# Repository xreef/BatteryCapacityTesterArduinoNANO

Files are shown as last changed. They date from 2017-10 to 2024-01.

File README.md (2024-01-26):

# Battery Capacity Tester Arduino NANO compatible #

Learn how to check battery capacity with Arduino, including essential techniques for temperature monitoring and selecting the right battery type, in my detailed article:

Checking Battery Capacity with Arduino: Temperature Monitoring and Type Selection (https://mischianti.org/checking-battery-capacity-with-arduino-temperature-monitoring-and-type-selection/)

[Link to the article](https://mischianti.org/checking-battery-capacity-with-arduino-temperature-monitoring-and-type-selection/)

This guide is a valuable resource for anyone interested in Arduino-based battery management and monitoring systems.

Battery capacity tester.
With this device you can check the 18650 battery capacity. For safe I added with thermistor the temperature of power resistance and battery to prevent explosion.
I'm doing some change from original project:
v0.1
 - VCC of Arduino now It's automatically calculated;
 - Added variable to change setting in more confortable way.
 - Added percentage of discharging
 - Added temperature of battery and power resistor
 
v0.2
 - Added possiblity of battery selection
 - Created prototype board (Look the schema), screen, button and speaker is out of board because in the future I'd like to create a package. 
  - Added manage of temperature limit for power resistor.to block when raise 70°.

In v0.2 to support various type of battery I created a struct that must be filled with battery name, min voltage, e max voltage *(I need help to fill :P)*.
```cpp
// Structure of battery type
struct BatteryType {
	char name[10];
	float maxVolt;
	float minVolt;
};

#define BATTERY_TYPE_NUMBER 4
BatteryType batteryTipes[BATTERY_TYPE_NUMBER] = {
		{ "18650", 4.3, 2.9 },
		{ "17550", 4.3, 2.9 },
		{ "14500", 4.3, 2.75 },
		{ "6v Acid", 7.2, 6.44  }
};
```
Now I use 10k resistor for voltage read, if you want change voltage support you must change this value *(explain better next)*:
```cpp
// Battery voltage resistance
#define BAT_RES_VALUE_GND 10.0
#define BAT_RES_VALUE_VCC 10.0
// Power resistor voltage resistance
#define RES_RES_VALUE_GND 10.0
#define RES_RES_VALUE_VCC 10.0
```
If you don't use thermistor set to false this:
```cpp
#define USING_BATTERY_TERMISTOR true
#define USING_RESISTO_TERMISTOR true
```
If you use a different i2c display you must rewrite this method:
```cpp
void draw(void);
```

In project you can find fritzing, schema, photo and other.

*I use generic character display, and I build the i2c controller and use It with my custom library, but if you want You can take a normal i2c controller (less than 1€) with standard library, the code remain the same.*
*All code of display is in draw function so you can change that without change other.*

Created from an idea of [OpenGreenEnergy](http://www.instructables.com/id/DIY-Arduino-Battery-Capacity-Tester-V10-/).

## Realization ##
To measuring voltage we use the principle of Voltage divider, more information on:
[Wikipedia](https://en.wikipedia.org/wiki/Voltage_divider) or [Blog](https://startingelectronics.org/articles/arduino/measuring-voltage-with-arduino/), in simple word this code 
```cpp
batVolt = (sample1 / (1023.0 - ((batResValueGnd / (batResValueVolt + batResValueGnd)) * 1023.0))) * vcc;
```
measure battery voltage,
`batResValueGnd / (batResValueVolt + batResValueGnd)` this is the multipler factor of the reading voltage, I inserted 2 resistance of `batResValueVolt` and `batResValueGnd` ohom after and before the analog read wire;
`sample1 -->` is the average analog readings;
`vcc -->` reference arduino voltage;
`1023.0 -->` is the reference maximun value of analog read (arduino analog read go from 0 to 1023)
	
The principle is that we measure the voltage afther and before the power resistor and so we can calculate milliampere that consumes the battery.

The MOSFET is used to stard and stop battery drain from power resistor.
I'm pretty scary, so I inserted 2 thermistors to monitorage battery and power resistor temperature.

### Versione v0.2 ###
---

**On prototype board:**
I create a prototype board very extendible, but for now I use only minimal set of pin (in future led and other button).
If you want support voltage greater than 10v you must change the resistor value of Battery and Resistance in according to the formula
`(BAT_RES_VALUE_GND / (BAT_RES_VALUE_VCC + BAT_RES_VALUE_GND)` in the schema `Resistor power voltage GND 1/2 / (Resistor power voltage 2/2 + Resistor power voltage GND 1/2)`.

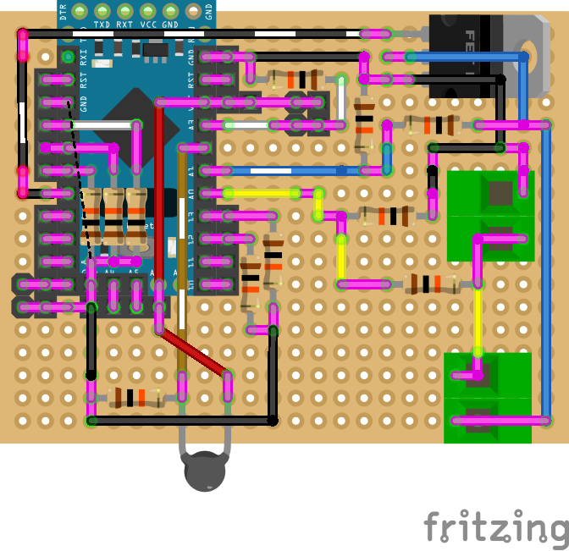
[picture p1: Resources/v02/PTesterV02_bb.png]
Prototype


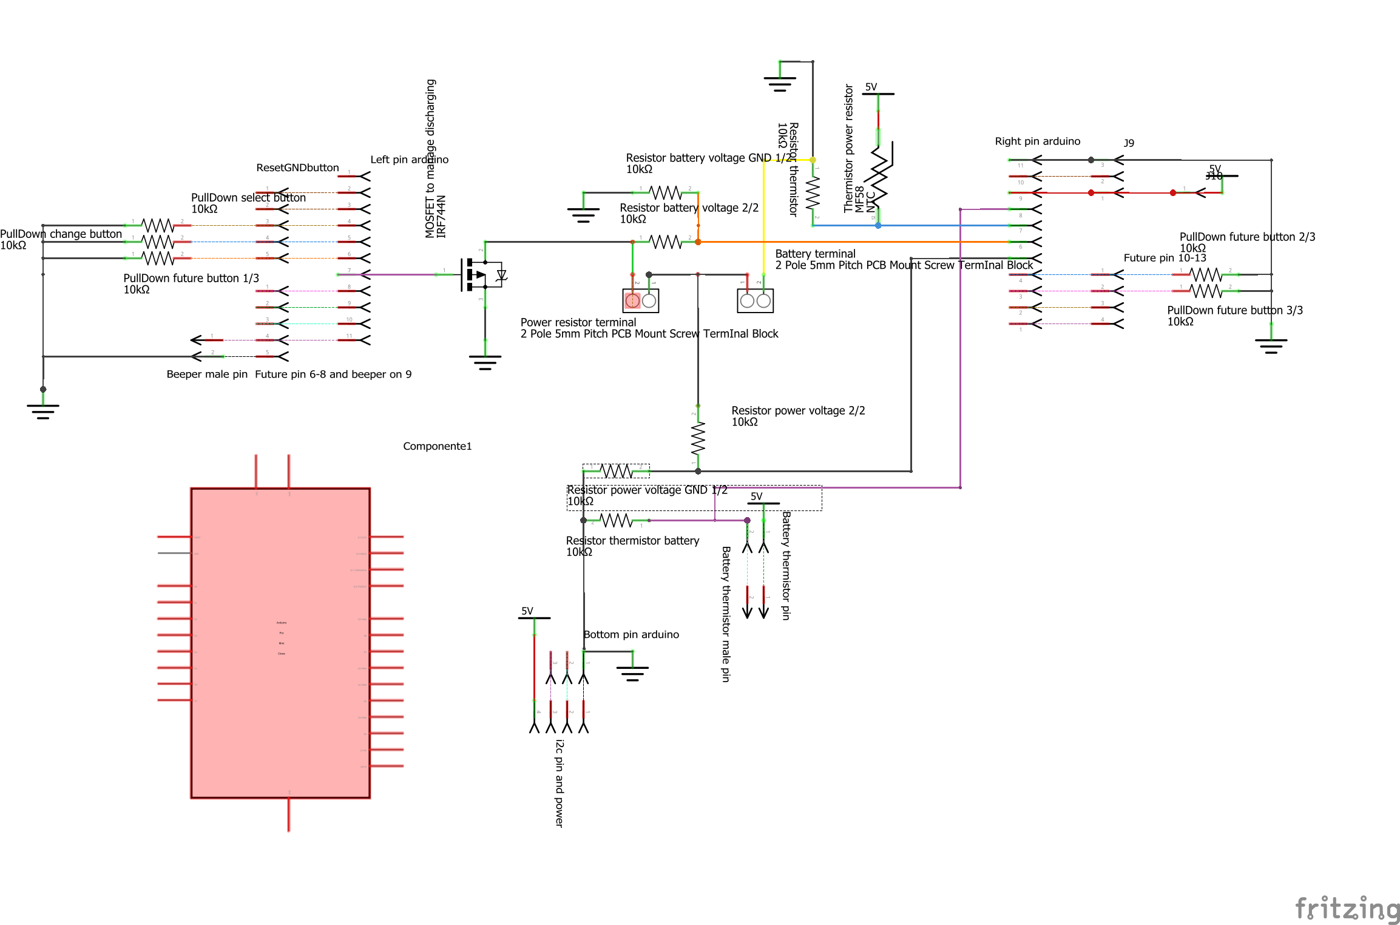
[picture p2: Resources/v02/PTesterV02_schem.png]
Prototype schema


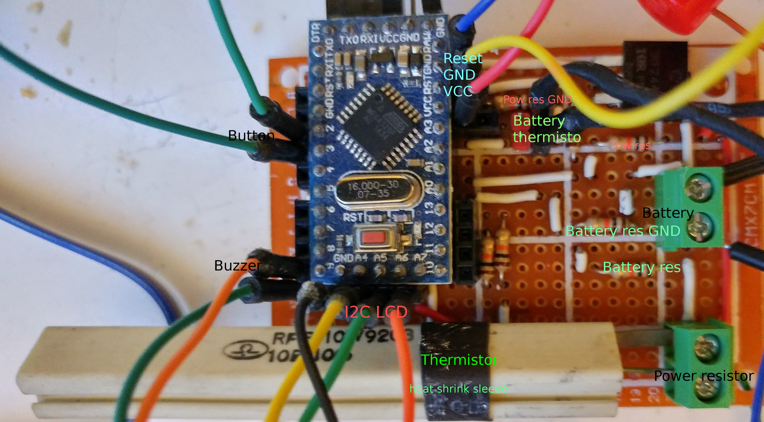
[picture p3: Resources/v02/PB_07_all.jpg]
Prototype real


**Shopping List**

| Amount | Part Type | Properties |
| --- | --- | --- |
| 2 |  5mm Screw TermInal [eBay](https://www.ebay.com/itm/20pcs-2-Pole-5mm-Pitch-PCB-Mount-Screw-TermInal-Block-8A-250V-LW-SZUS/181932294528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) | pin spacing 0.2in (5.08mm);  2 Pole 5mm Pitch PCB Mount Screw TermInal Block 8A 250V LW SZUS |
| 1 | Arduino Pro Mini clone (compatible Nano) [eBay](https://www.ebay.com/itm/New-design-Pro-Mini-atmega328-5V-16M-Replace-ATmega128-Arduino-Compatible-Nano/171558370113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) | tipo Arduino Pro Mini (Clone comp Nano); variant variant 1 |
| 1 | Basic FET P-Channel **IRF744N or IRLZ44N** [eBay](https://www.ebay.com/itm/5PCS-IRLZ44N-TO-220-IRLZ44-TO220-IRLZ44NPBF-Effect-Transistor/192345139104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) | package TO220 [THT]; tipo p-channel |
| 11 | 10kΩ Resistor | bands 4; pin spacing 400 mil; tolerance ±5%; package THT; resistenza 10kΩ |
| 1 | Temperature Sensor (Thermistor) [eBay](https://www.ebay.com/itm/10Pcs-Temperature-Sensor-Ntc-Mf58-3950-B-10K-Ohm-5-Thermistor-New-Ic-T/232317930330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) | package THT; thermistor type NTC; resistance at 25° **10kΩ**; tipo thermistor |
| * | Generic male header | form ♂ (male); pin spacing 0.1in (2.54mm); package THT; row single; hole size 1.0mm,0.508mm; pins 2 |
| * | Generic female header | form ♀ (female); pin spacing 0.1in (2.54mm); package THT; row single; hole size 1.0mm,0.508mm; pins 2 |
| PerfBoard board | Prototype board [eBay](https://www.ebay.com/itm/Novelty-Universal-Bakelite-Circuit-Board-DIY-Prototype-PCB-Rectangle-Device-5pcs/142528992310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) | 24x18  |

[Complete list of all part](https://github.com/xreef/BatteryCapacityTesterArduinoNANO/blob/master/Resources/v02/PTesterV02_bom.html)

Soldering prototype:

[//]: # (![Pin up]&#40;https://github.com/xreef/BatteryCapacityTesterArduinoNANO/blob/master/Resources/v02/PB_02_pin_up.jpg&#41;)

[//]: # (![Pin bottom]&#40;https://github.com/xreef/BatteryCapacityTesterArduinoNANO/blob/master/Resources/v02/PB_01_pin_bottom.jpg&#41;)

[//]: # (![Pull up]&#40;https://github.com/xreef/BatteryCapacityTesterArduinoNANO/blob/master/Resources/v02/PB_03_pulldown_up.jpg&#41;)

[//]: # (![pull down]&#40;https://github.com/xreef/BatteryCapacityTesterArduinoNANO/blob/master/Resources/v02/PB_05_pulldown_connect_bottom.jpg&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;)
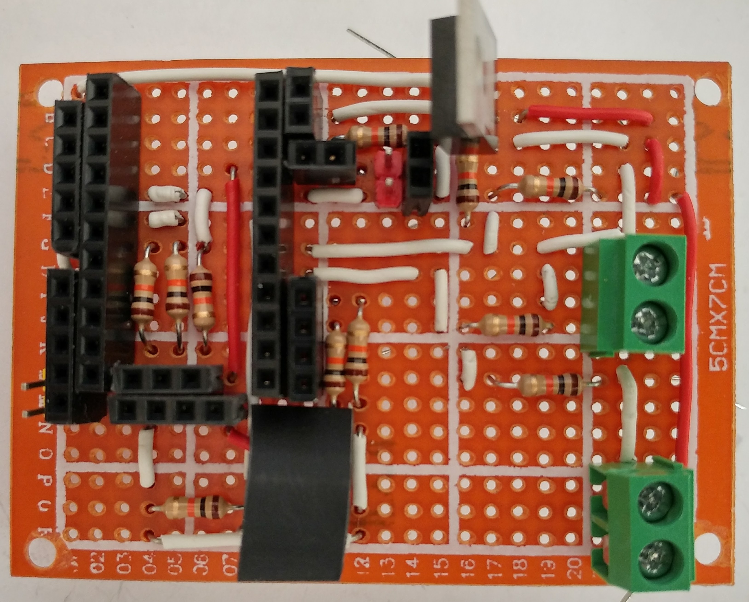
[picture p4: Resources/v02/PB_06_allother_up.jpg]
All up

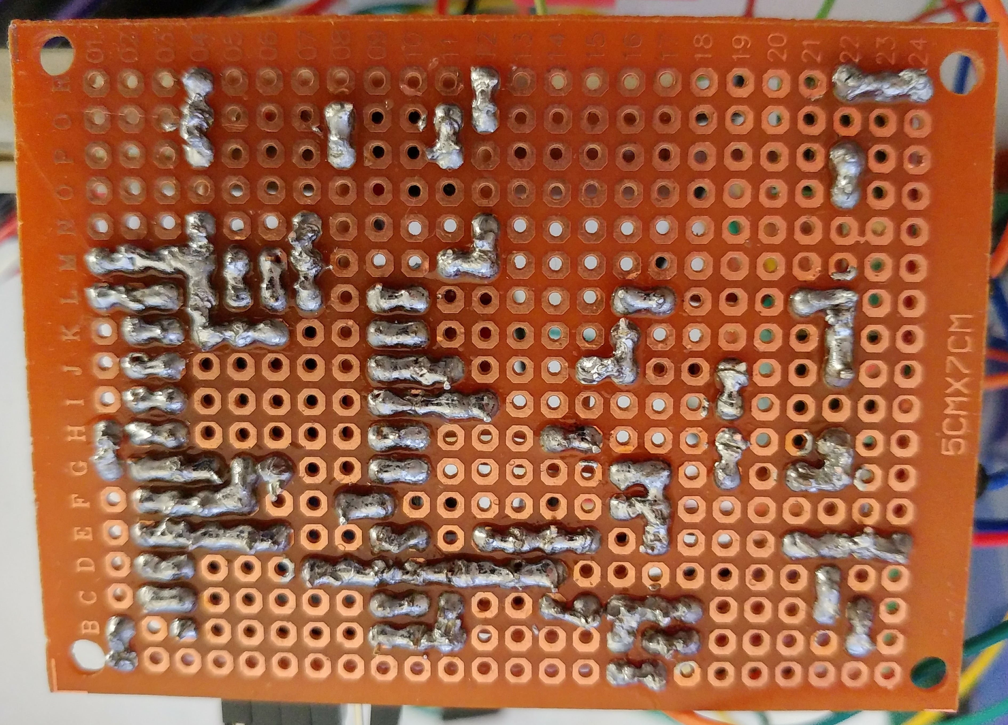
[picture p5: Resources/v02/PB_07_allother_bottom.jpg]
All bottom

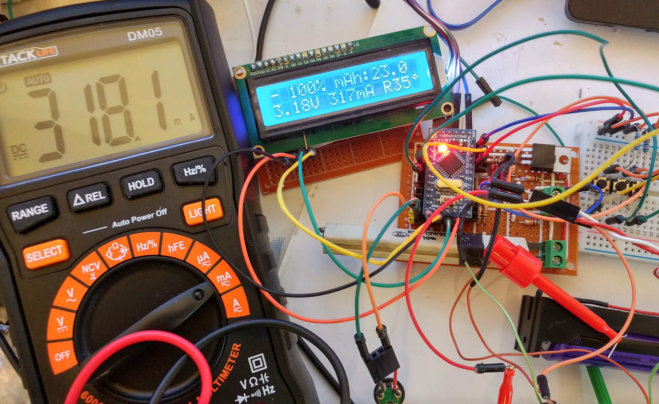
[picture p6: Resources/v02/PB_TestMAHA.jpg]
PB_TestMAHA


**Display**

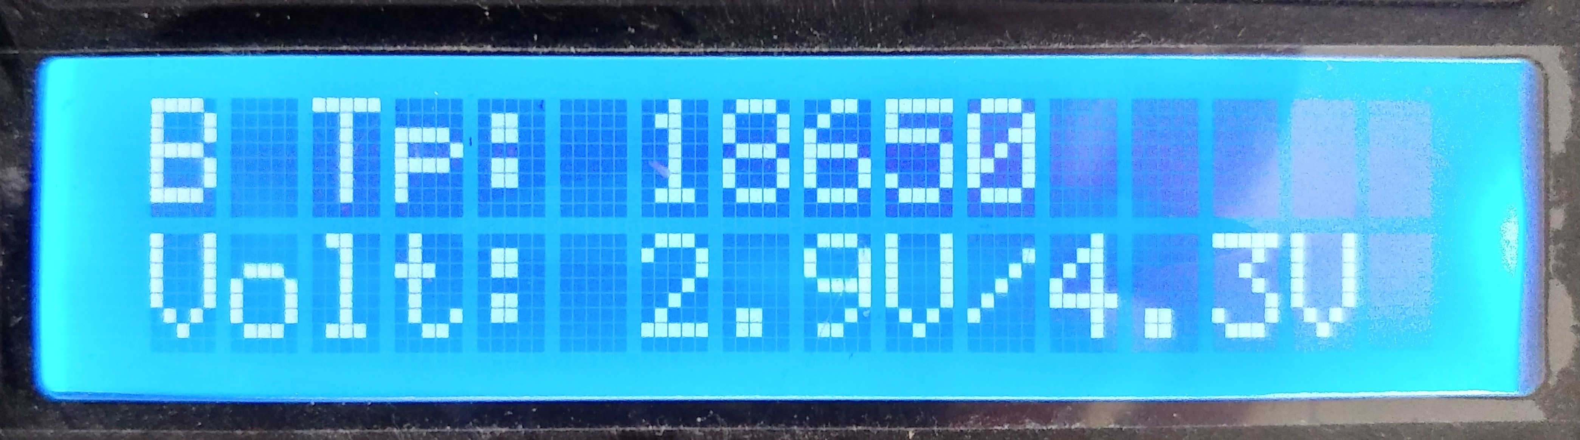
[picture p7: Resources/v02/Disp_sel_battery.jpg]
Sel battery

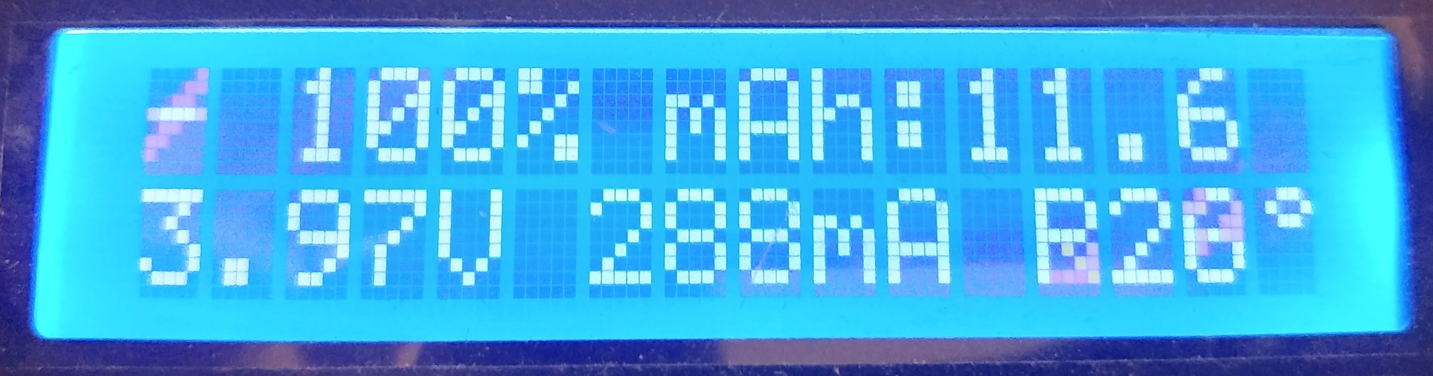
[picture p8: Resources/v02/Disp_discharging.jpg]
Discharging

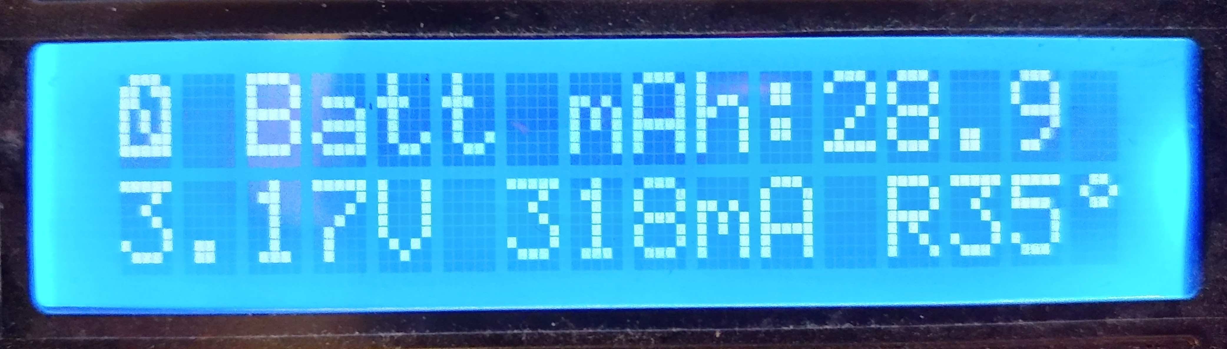
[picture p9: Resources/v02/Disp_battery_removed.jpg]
Battery removed

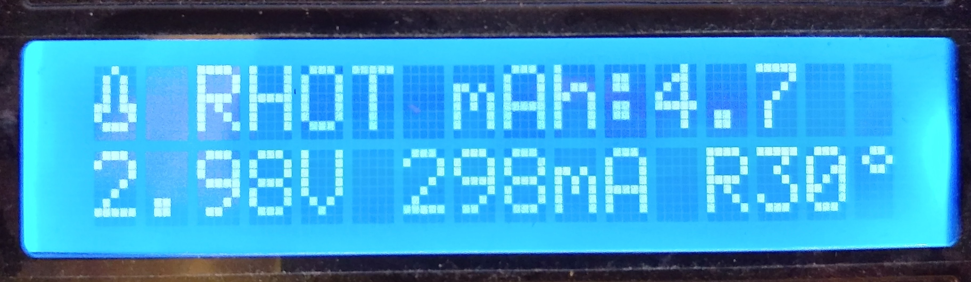
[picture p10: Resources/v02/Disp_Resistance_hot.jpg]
Resistance hot


**On breadboard:**

[//]: # (![Breadboard]&#40;https://github.com/xreef/BatteryCapacityTesterArduinoNANO/blob/master/Resources/v02/BTesterV02_bb.png&#41;)

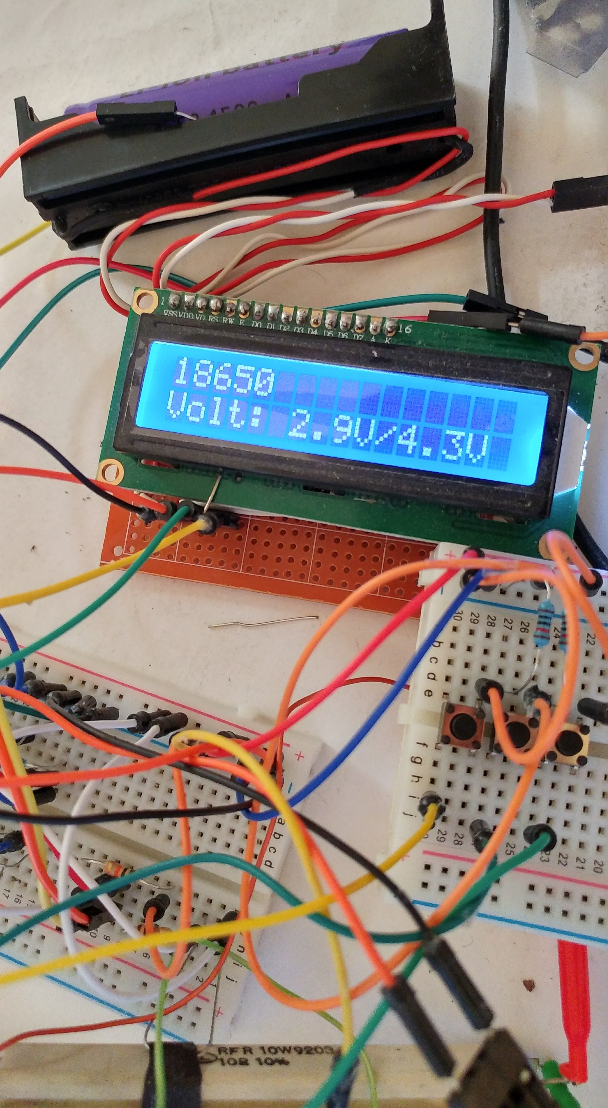
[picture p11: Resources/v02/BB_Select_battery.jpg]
Battery selection


**Serial output for debug:**

```
Volt: 2.94V - B Volt: 2.94V - Res Volt: 0.00V - Curr: 292mA - mAh: 219.4 - DISCHARGING: 1 - Battery temp: 19.47 - Resistance temp: 32.28
Volt: 2.94V - B Volt: 2.94V - Res Volt: 0.00V - Curr: 292mA - mAh: 219.4 - DISCHARGING: 1 - Battery temp: 19.47 - Resistance temp: 32.24
Volt: 2.94V - B Volt: 2.94V - Res Volt: 0.00V - Curr: 292mA - mAh: 219.4 - DISCHARGING: 1 - Battery temp: 19.44 - Resistance temp: 32.28
Volt: 2.92V - B Volt: 2.92V - Res Volt: 0.00V - Curr: 292mA - mAh: 219.7 - DISCHARGING: 1 - Battery temp: 19.49 - Resistance temp: 32.28
Volt: 2.94V - B Volt: 2.94V - Res Volt: 0.00V - Curr: 292mA - mAh: 219.7 - DISCHARGING: 1 - Battery temp: 19.46 - Resistance temp: 32.26
Volt: 2.94V - B Volt: 2.94V - Res Volt: 0.00V - Curr: 292mA - mAh: 219.7 - DISCHARGING: 1 - Battery temp: 19.42 - Resistance temp: 32.28
Volt: 2.92V - B Volt: 2.92V - Res Volt: 0.00V - Curr: 292mA - mAh: 219.7 - DISCHARGING: 1 - Battery temp: 19.46 - Resistance temp: 32.22
Volt: 2.94V - B Volt: 2.94V - Res Volt: 0.00V - Curr: 294mA - mAh: 220.0 - DISCHARGING: 1 - Battery temp: 19.46 - Resistance temp: 32.26
```

[//]: # (### Version v0.1 ###)

[//]: # (---)

[//]: # ()
[//]: # (## Wire schema v0.1 ##)

[//]: # (![Breadboard schema]&#40;https://github.com/xreef/BatteryCapacityTesterArduinoNANO/blob/master/Resources/v01/BTester_bb.png&#41;)

[//]: # (![Schema]&#40;https://github.com/xreef/BatteryCapacityTesterArduinoNANO/blob/master/Resources/v01/BTester_schem.png&#41;)

## Assembly list ##
| Label | Part Type | Properties |
| --- | --- | --- |
| **(LCD bb)** Display* | LCD screen | pins 16; tipo Character |
| **(LCD bb)** i2c controller* | PCF8574 | tipo PCF8574; package DIP16 [THT] |
| **(LCD bb)** 10K Trimmer potentiometer* | TRIMPOT | variant variant 2; package trimpot_pth_s3_lock_3386P |
| **(LCD bb)** 2N2222* | NPN-Transistor | tipo NPN (EBC); package TO92 [THT]; part number 2N2222 |
| 18650 Battery | LIPO-1000mAh | variant 1000mAh; package lipo-1000 |
| Beeper | Piezo Speaker |
| For battery | Screw terminal - 2 pins | pin spacing 0.1in (2.54mm); pins 2; hole size 1.0mm,0.508mm; package THT |
| For power resistor | Screw terminal - 2 pins | pin spacing 0.1in (2.54mm); pins 2; hole size 1.0mm,0.508mm; package THT |
| IRF744N | Basic FET N-Channel | tipo n-channel; package TO220 [THT] |
| MF58 | Temperature Sensor (Thermistor) | resistance at 25° 10kΩ; tipo thermistor; package THT; thermistor type NTC |
| MF58 | Temperature Sensor (Thermistor) | resistance at 25° 10kΩ; tipo thermistor; package THT; thermistor type NTC |
| Microcontroller | Arduino Pro Mini clone (compatible Nano) [eBay](https://www.ebay.com/itm/New-design-Pro-Mini-atmega328-5V-16M-Replace-ATmega128-Arduino-Compatible-Nano/171558370113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) | variant variant 1; tipo Arduino Pro Mini (Clone comp Nano) |
| Power resistor | 10kΩ Resistor | pin spacing 400 mil; bands 5; resistenza 10kΩ; tolerance ±5%; package THT; part number Power resistor |
| Resistance of battery volt. 1/2 | 10kΩ Resistor | pin spacing 400 mil; bands 4; resistenza 10kΩ; tolerance ±5%; package THT |
| Resistance of battery volt. 2/2 | 10kΩ Resistor | pin spacing 400 mil; bands 4; resistenza 10kΩ; tolerance ±5%; package THT |
| Resistance of power res. volt. 1/2 | 10kΩ Resistor | pin spacing 400 mil; bands 4; resistenza 10kΩ; tolerance ±5%; package THT |
| Resistance of power res. volt. 2/2 | 10kΩ Resistor | pin spacing 400 mil; bands 4; resistenza 10kΩ; tolerance ±5%; package THT |
| Thermistor battery resistance | 10kΩ Resistor | pin spacing 400 mil; bands 4; resistenza 10kΩ; tolerance ±5%; package THT |
| Thermistor power res. resistance | 10kΩ Resistor | pin spacing 400 mil; bands 4; resistenza 10kΩ; tolerance ±5%; package THT |

## Shopping List

| Amount | Part Type | Properties |
| --- | --- | --- |
| 1* | LCD screen | pins 16; tipo Character |
| 1* | PCF8574 | tipo PCF8574; package DIP16 [THT] |
| 1* | TRIMPOT | variant variant 2; package trimpot_pth_s3_lock_3386P |
| 1* | NPN-Transistor | tipo NPN (EBC); package TO92 [THT]; part number 2N2222 |
| 1 | LIPO-1000mAh | variant 1000mAh; package lipo-1000 |
| 1 | Piezo Speaker |
| 2 | Screw terminal - 2 pins | pin spacing 0.1in (2.54mm); pins 2; hole size 1.0mm,0.508mm; package THT |
| 1 | Basic FET N-Channel | tipo n-channel; package TO220 [THT] |
| 2 | Temperature Sensor (Thermistor) | resistance at 25° 10kΩ; tipo thermistor; package THT; thermistor type NTC |
| 1 | Arduino Pro Mini clone (compatible Nano) | variant variant 1; tipo Arduino Pro Mini (Clone comp Nano) |
| 1 | 10kΩ Resistor | pin spacing 400 mil; bands 5; resistenza 10kΩ; tolerance ±5%; package THT; part number Power resistor |
| 6 | 10kΩ Resistor | pin spacing 400 mil; bands 4; resistenza 10kΩ; tolerance ±5%; package THT |

*\* Only if you want assembly LCD i2c character controller*

**Breadboard**

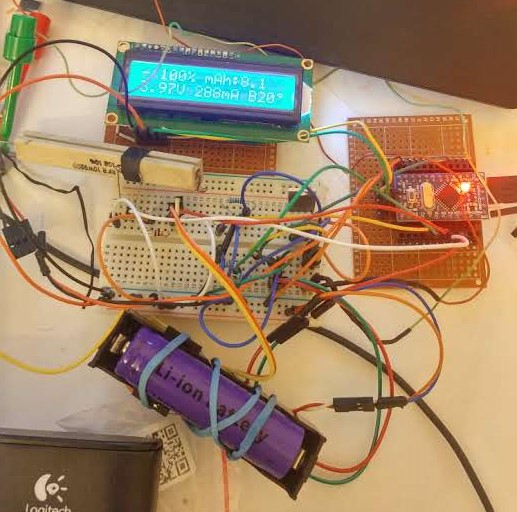
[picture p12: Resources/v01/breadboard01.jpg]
Breadboard

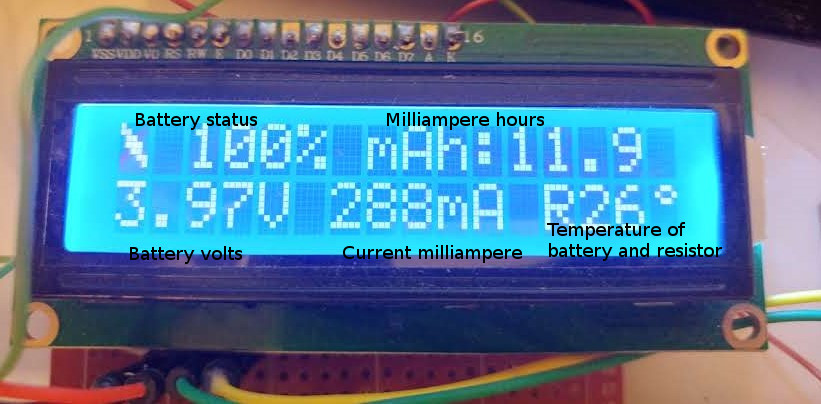
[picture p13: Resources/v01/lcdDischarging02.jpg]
lcd on discharging


Thermistor on power resistor (heat shrink sleeve to hold).

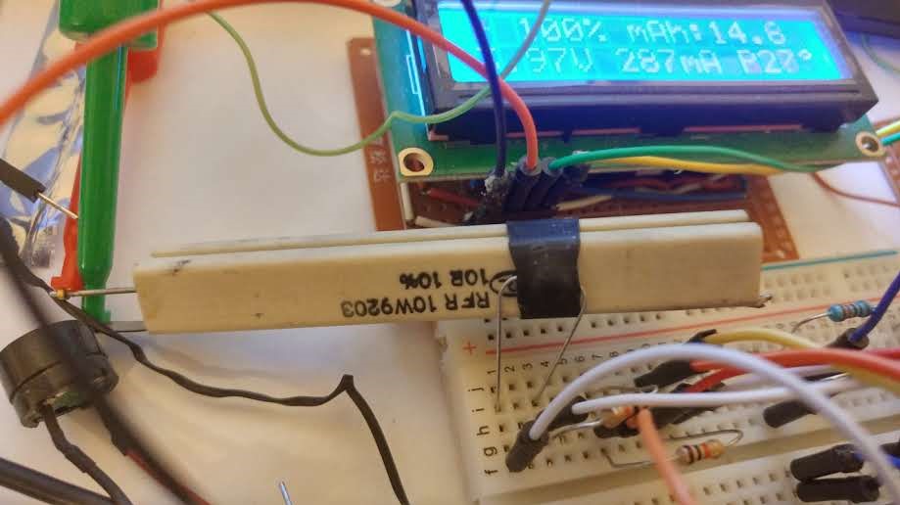
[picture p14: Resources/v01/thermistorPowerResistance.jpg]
Thermistor on power resistance


Thermistor on battery.

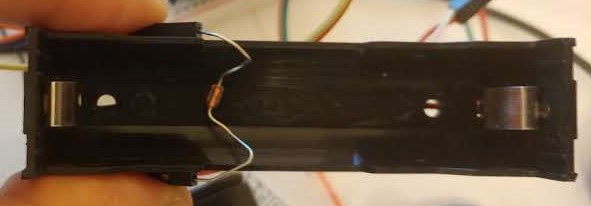
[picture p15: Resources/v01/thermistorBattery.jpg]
Thermistor on battery


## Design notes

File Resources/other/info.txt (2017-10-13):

http://www.instructables.com/id/DIY-Arduino-Battery-Capacity-Tester-V10-/

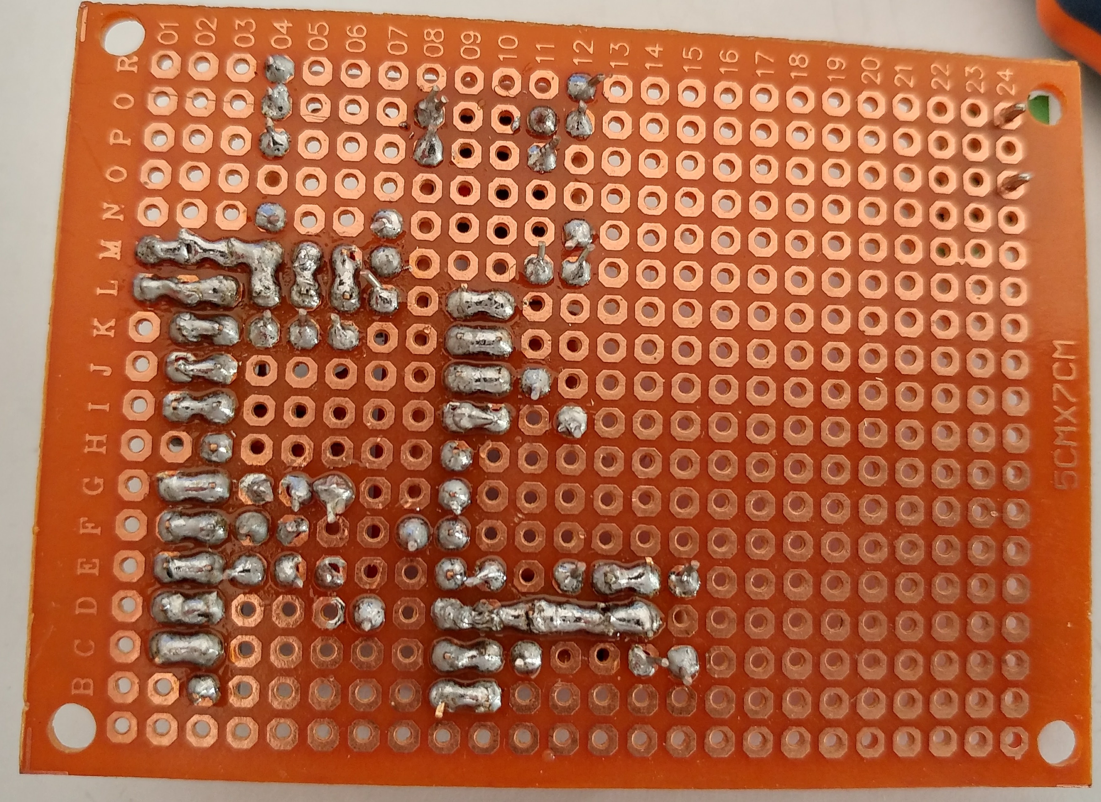
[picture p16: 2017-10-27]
Resources/v02/PB_04_pulldown_bottom.jpg

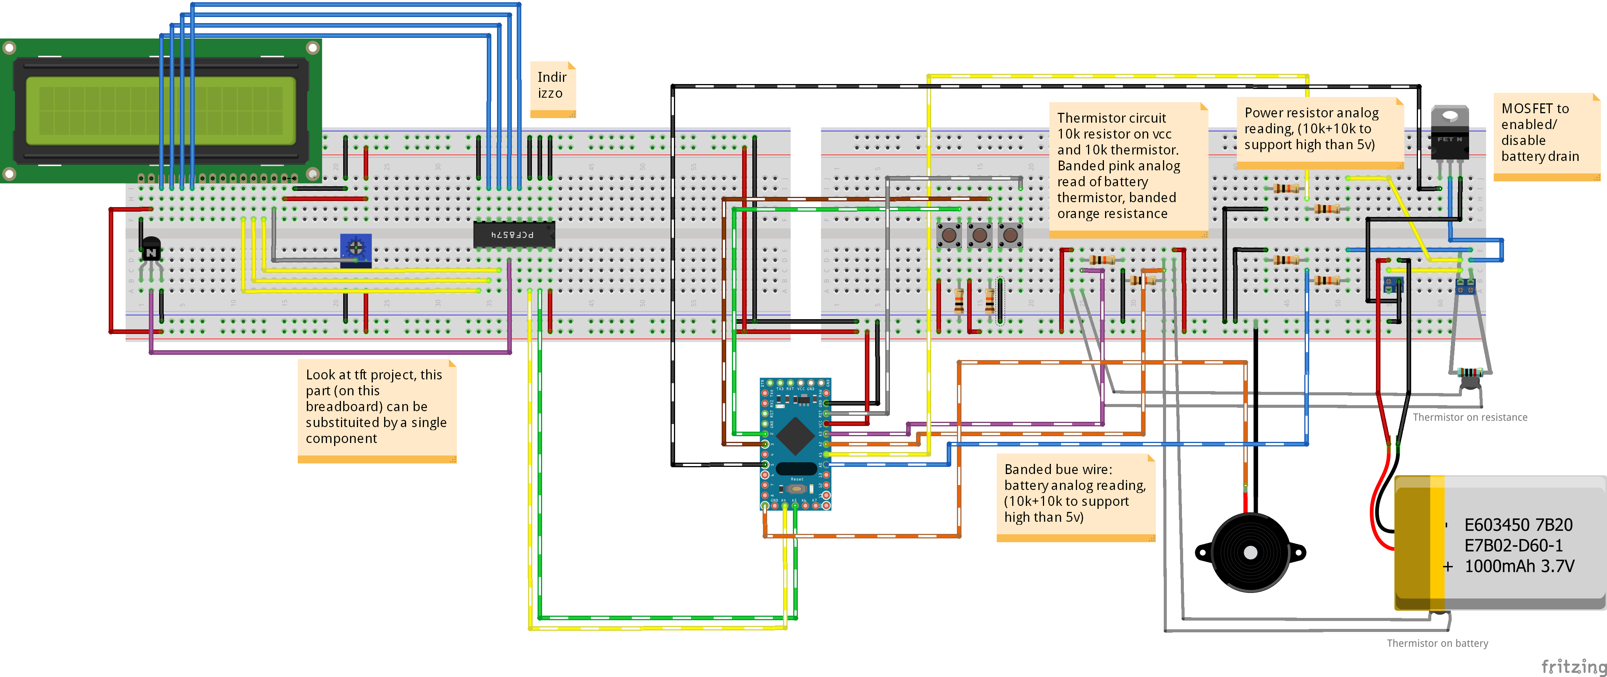
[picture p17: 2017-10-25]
Resources/v02/BTesterV02_bb.png

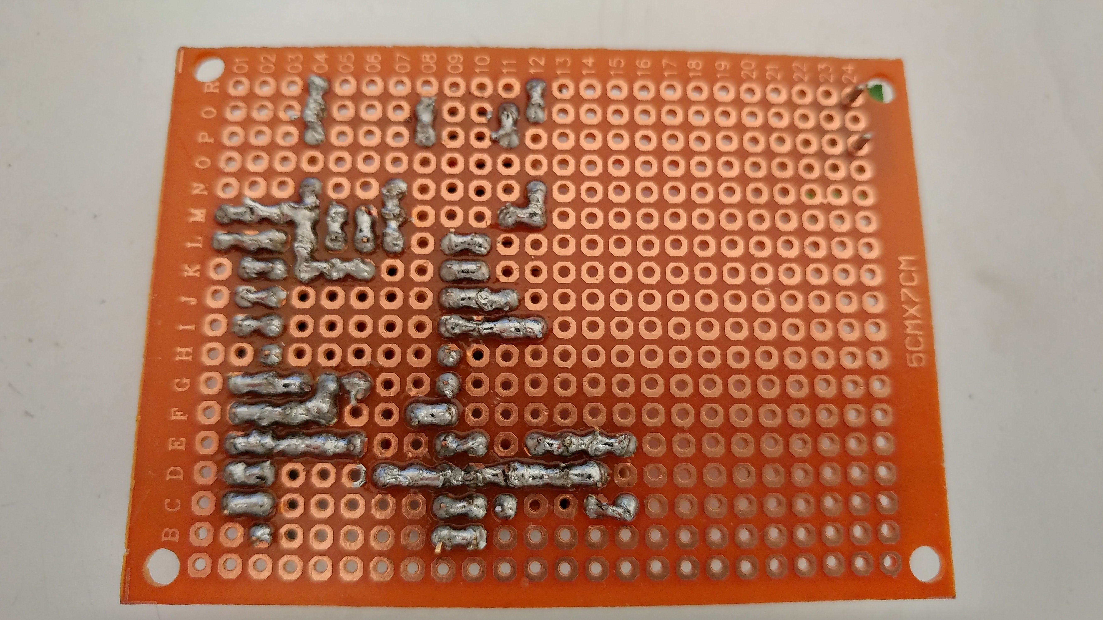
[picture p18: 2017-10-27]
Resources/v02/PB_05_pulldown_connect_bottom.jpg

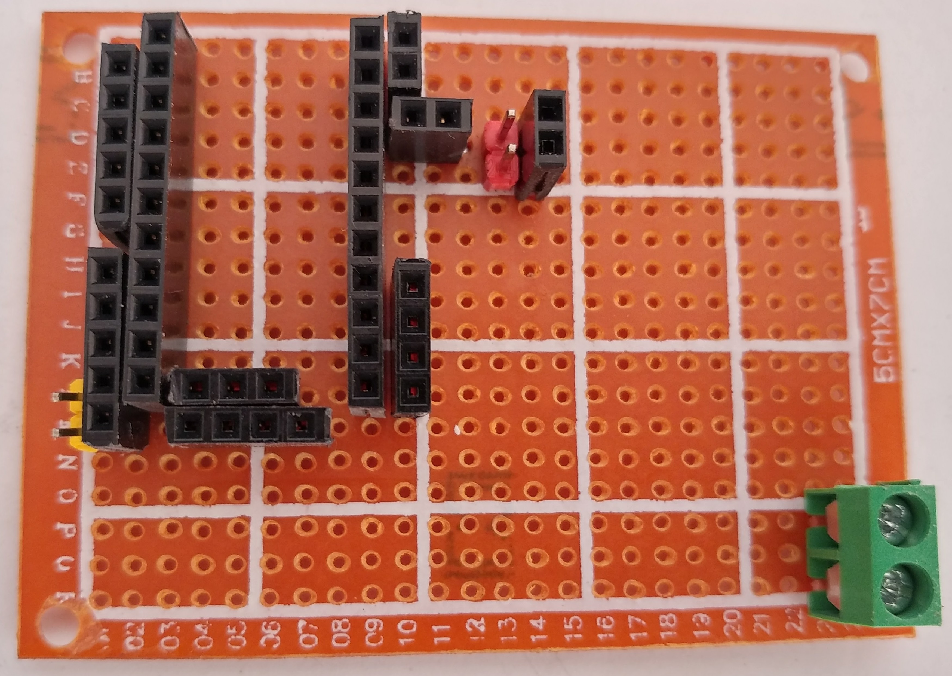
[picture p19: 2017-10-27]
Resources/v02/PB_02_pin_up.jpg

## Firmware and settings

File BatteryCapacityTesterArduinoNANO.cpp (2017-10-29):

// Do not remove the include below
#include "BatteryCapacityTesterArduinoNANO.h"

#include "LiquidCrystal_I2C.h"
#include "Thermistor.h"
#include <Wire.h>

#define CHANGE_BATTERY_BUTTON 2
#define SELECT_BATTERY_BUTTON 3

#define MOSFET_PIN 5
#define BAT_PIN A0
#define RES_PIN A1
#define BATTERY_THERM_PIN A3
#define RESISTA_THERM_PIN A2
#define BUZZER_PIN 9

#define BATTERY_MAX_TEMP 50
#define RESISTANCE_MAX_TEMP 69 // 70° on datasheet (Derating resistors)
#define TEMP_TO_REMOVE_ON_MAX_TEMP 20

// Battery voltage resistance
#define BAT_RES_VALUE_GND 10.0
#define BAT_RES_VALUE_VCC 10.0
// Power resistor voltage resistance
#define RES_RES_VALUE_GND 10.0
#define RES_RES_VALUE_VCC 10.0

#define NO_BATTERY_VOLTAGE 1

#define USING_BATTERY_TERMISTOR true
#define USING_RESISTO_TERMISTOR true

#define NUMBER_OF_LOW_TO_RAISE  5
#define WAIT_AFTER_LOW 4000

uint8_t lowRaised = 0;

float capacity = 0.0; 	// capacity in mAh
float resValue = 10.0;  // Resistor Value in Ohm
float vcc = 5.04; 		// Voltage of Arduino 5V pin ( overwritten by function )
float minVoltageDropoutTolerance = 0.1; // If min value declared is 2.9 i apply 2.8 to compensate voltage oscillation
//float tolerance = 0.2; 	// When raise first time the low voltage at next check I apply this tolerance to not restart if It's raise the value
float current = 0.0; 	// current in Amp
float mA = 0;         	// current in mA
float batVolt = 0.0;  	// Battery Voltage
float realBatVolt = 0.0;// Battery voltage + resistance voltage
float resVolt = 0.0;  	// Voltage at lower end of the Resistor

// Valiable to manage some behaivor
int prevStatus = 0; 				// Last state
bool dischargingStarted = false;	// Fist time starting discharging
float startingVcc = 4.2; 			// Voltage at the start of discharging (overwritten at first time)

// Structure of battery type
struct BatteryType {
	char name[10];
	float maxVolt;
	float minVolt;
};

#define BATTERY_TYPE_NUMBER 4
BatteryType batteryTipes[BATTERY_TYPE_NUMBER] = {
		{ "18650", 4.3, 2.9 },
		{ "17550", 4.3, 2.9 },
		{ "14500", 4.3, 2.75 },
		{ "6v Acid", 6.50, 5.91  }
};

// Variable to use in discharging time
float batHigh = 4.3; 	// Battery High Voltage
float batLow = 2.9; 	// Discharge Cut Off Voltage

// Value of button
// button of change battery
uint8_t buttonChangeState = LOW;
// button of select battery
uint8_t buttonSelectState = LOW;

// Temporary selected battery
uint8_t tmpBatterySelected = 0;
// Selected battery
int8_t batterySelected = -1;
// First time must refresh display
bool displayRefresh = false;

unsigned long previousMillis = 0; 		// Previous time in ms
unsigned long millisPassed = 0;  		// Using this variable to update screen more than update values (for animated effect)
unsigned long waitMillisPassed = 3000;  // current time in ms
int x = 0;
int row = 0;

// Variable to hold mosfet status
int mosfetStatus = LOW;

// Inizialize thermistor
Thermistor thermBattery(BATTERY_THERM_PIN);
Thermistor thermResistance(RESISTA_THERM_PIN);

// Inizialize display
LiquidCrystal_I2C lcd(0x38, 16, 2);
// Additional display character
int loadLenght = 3;
byte loader[][8] = { { // 0 loader
		B00001,
		B00011,
		B00110,
		B01110,
		B01100,
		B11000,
		B10000 }, { // 1 loader
		B00000,
		B00000,
		B00000,
		B11111,
		B00000,
		B00000,
		B00000 }, { // 2 loader
		B10000,
		B11000,
		B01100,
		B01110,
		B00110,
		B00011,
		B00001 }, { // no battery load + 0
		B01110,
		B11011,
		B11001,
		B10101,
		B10101,
		B10011,
		B11111 }, { // arrow down load+1
		B01110,
		B01110,
		B01110,
		B01110,
		B11111,
		B01110,
		B00100 }, { // arrow up load+2
		B00100,
		B01110,
		B11111,
		B01110,
		B01110,
		B01110,
		B01110 }, {  // ° load+3
		B00110,
		B01001,
		B00110,
		B00000,
		B00000,
		B00000,
		B00000, }, {  // thermometer load+4
		B00100,
		B01010,
		B01010,
		B01010,
		B11011,
		B10001,
		B01110, } };

uint8_t lastTempVisualizedBattery = 0;
int loadingCursor = 0;

float batteryTemp = NAN;
float resistanceTemp = NAN;

bool batteryMaxTempRaised = false;
bool resistorMaxTempRaised = false;

void draw(void);
void beep(unsigned char delay_time);
long readVcc(void);

void setup() {
	Serial.begin(115200);

	pinMode(MOSFET_PIN, OUTPUT);
	pinMode(BUZZER_PIN, OUTPUT);
	digitalWrite(MOSFET_PIN, LOW);  // MOSFET is off during the start
	mosfetStatus = LOW;  			// MOSFET status is off during the start
	Serial.println("CLEARDATA");

	// Inizialize LCD
	lcd.init();
	lcd.clear();
	int i;
	for (i = 0; i < loadLenght + 5; i++) {
		lcd.createChar(i, loader[i]);
	}
	lcd.setBacklight(LOW);

	pinMode(SELECT_BATTERY_BUTTON, INPUT);
	pinMode(CHANGE_BATTERY_BUTTON, INPUT);
}

// The loop function is called in an endless loop
void loop() {
	vcc = readVcc() / 1000.0;

	//************ Measuring Battery Voltage ***********
	float sample1 = 0;
	float sample2 = 0;

	for (int i = 0; i < 100; i++) {
		sample1 = sample1 + analogRead((uint8_t)BAT_PIN); //read the voltage from the divider circuit
		delay(2);
	}
	sample1 = sample1 / 100;
	batVolt = (sample1
			/ (1023.0
					- ((BAT_RES_VALUE_GND / (BAT_RES_VALUE_VCC + BAT_RES_VALUE_GND))
							* 1023.0))) * vcc;

	// *********  Measuring Resistor Voltage ***********
	for (int i = 0; i < 100; i++) {
		sample2 = sample2 + analogRead((uint8_t)RES_PIN); //read the voltage from the divider circuit
		delay(2);
	}
	sample2 = sample2 / 100;
	resVolt = (sample2
			/ (1023.0
					- ((RES_RES_VALUE_GND / (RES_RES_VALUE_VCC + RES_RES_VALUE_GND))
							* 1023.0))) * vcc;

	realBatVolt = (mosfetStatus == HIGH) ? batVolt + resVolt : batVolt;

	// ************* Read thermistor temperature ***********************
	batteryTemp = thermBattery.readTemperature();
	resistanceTemp = thermResistance.readTemperature();

	//********************* Checking the different conditions *************
	// No battery selected
	if (batterySelected==-1){
		buttonChangeState = digitalRead(CHANGE_BATTERY_BUTTON);
		if (buttonChangeState==HIGH) {
			tmpBatterySelected++;
			if (tmpBatterySelected>=BATTERY_TYPE_NUMBER){
				tmpBatterySelected = 0;
			}
			displayRefresh = true;
		}else{
			displayRefresh = false;
		}

		buttonSelectState = digitalRead(SELECT_BATTERY_BUTTON);
		if (buttonSelectState==HIGH) {
			batterySelected = tmpBatterySelected;
			batHigh = batteryTipes[tmpBatterySelected].maxVolt; // Battery High Voltage
			batLow = batteryTipes[tmpBatterySelected].minVolt - minVoltageDropoutTolerance; // Discharge Cut Off Voltage
//			startingVcc = batHigh;
			// I put batt low value so I show 0% until the correct voltage is grabbed
			startingVcc = batLow;
		}
		delay(10);

		// Reset millis
		previousMillis = millis();
	// Temperature warning
	}else if (
			(USING_BATTERY_TERMISTOR &&
					(
							batteryTemp > BATTERY_MAX_TEMP
							|| (batteryMaxTempRaised && batteryTemp > (BATTERY_MAX_TEMP-TEMP_TO_REMOVE_ON_MAX_TEMP))
					)
			)
			|| (USING_RESISTO_TERMISTOR &&
					(
							resistanceTemp > RESISTANCE_MAX_TEMP
							|| (resistorMaxTempRaised && resistanceTemp > (RESISTANCE_MAX_TEMP-TEMP_TO_REMOVE_ON_MAX_TEMP))
					)
				)
			) {
		if (batteryTemp > BATTERY_MAX_TEMP) batteryMaxTempRaised = true;
		if (resistanceTemp > RESISTANCE_MAX_TEMP) resistorMaxTempRaised = true;

		digitalWrite(MOSFET_PIN, LOW); // Turned Off the MOSFET // No discharge
		mosfetStatus = LOW;
		beep(50);
		beep(100);
		beep(200);
		delay(5000);

		// Reset millis
		previousMillis = millis();
	// Voltage too hight
	} else if (realBatVolt > batHigh) {
		digitalWrite(MOSFET_PIN, LOW); // Turned Off the MOSFET // No discharge
		mosfetStatus = LOW;
		beep(200);
		delay(1000);

		// Reset millis
		previousMillis = millis();
	// No battery
	} else if (realBatVolt < NO_BATTERY_VOLTAGE) {
		digitalWrite(MOSFET_PIN, LOW);
		mosfetStatus = LOW;
		beep(200);
		delay(1000);

		// Reset max battery voltage
		batteryMaxTempRaised = false;
		resistorMaxTempRaised = false;

		// Reset millis
		previousMillis = millis();
	// Voltage too low
	} else if (realBatVolt < batLow || lowRaised>NUMBER_OF_LOW_TO_RAISE) {
		// Reset max battery voltage
		batteryMaxTempRaised = false;
		resistorMaxTempRaised = false;

		// Now discharging is considered started when al least wone time is calculated maha
		// So need to check mosfet status if some people attach discharged battery to device
		if (dischargingStarted || mosfetStatus==HIGH) {
			dischargingStarted = true;
			if (lowRaised<=NUMBER_OF_LOW_TO_RAISE) lowRaised++; // To prevent overflow
		}

		digitalWrite(MOSFET_PIN, LOW);
		mosfetStatus = LOW;
		beep(200);
		delay(WAIT_AFTER_LOW);
	// Discharging ok
	} else if (realBatVolt > batLow && realBatVolt < batHigh
			&& (previousMillis == 0
					|| (millis() - previousMillis) > waitMillisPassed)) { // Check if the battery voltage is within the safe limit
		// Reset max battery voltage
		batteryMaxTempRaised = false;
		resistorMaxTempRaised = false;

		// startingVcc used to get percentage of discharging
		if (!dischargingStarted && mosfetStatus == HIGH) {
			startingVcc = realBatVolt;
			dischargingStarted = true;
		}

		// When battery is under discharging change his voltage and now I reset previous millis to have a resonable value
		if (mosfetStatus==LOW){
			digitalWrite(MOSFET_PIN, HIGH);
			mosfetStatus = HIGH;
			delay(2000);
			previousMillis = millis();
		}else{
			millisPassed = millis() - previousMillis;
			current = (batVolt - resVolt) / resValue;
			mA = current * 1000.0;
			capacity = capacity + mA * (millisPassed / 3600000.0); // 1 Hour = 3600000ms
			previousMillis = millis();
			row++;
			x++;
		}
		delay(1000);
	}

	draw();
}

bool firstTimeRefresh = true;
/************************ Display Draw Function *******************************************************
 * Change this if you use a different display
 */

void draw(void) {
	// First time of battery selected refresh lcd
	if (batterySelected!=-1 && prevStatus==0){
		lcd.clear();
	}

	// If not already select a battery type
	if (batterySelected==-1){
		if (displayRefresh || firstTimeRefresh){
			lcd.clear();

			lcd.setCursor(0, 0);
			lcd.print("B Tp: ");
			lcd.print(batteryTipes[tmpBatterySelected].name);
			lcd.setCursor(0, 1);
			lcd.print("Volt: ");
			lcd.print(batteryTipes[tmpBatterySelected].minVolt, 1);
			lcd.print("V/");
			lcd.print(batteryTipes[tmpBatterySelected].maxVolt,1 );
			lcd.print("V");

			firstTimeRefresh = false;
		}
	// If battery or resistance temp is out of range
//	}else if (batteryTemp > BATTERY_MAX_TEMP || resistanceTemp > RESISTANCE_MAX_TEMP) {
	}else if (
			(USING_BATTERY_TERMISTOR &&
					(
							batteryTemp > BATTERY_MAX_TEMP
							|| (batteryMaxTempRaised && batteryTemp > (BATTERY_MAX_TEMP-TEMP_TO_REMOVE_ON_MAX_TEMP))
					)
			)
			|| (USING_RESISTO_TERMISTOR &&
					(
							resistanceTemp > RESISTANCE_MAX_TEMP
							|| (resistorMaxTempRaised && resistanceTemp > (RESISTANCE_MAX_TEMP-TEMP_TO_REMOVE_ON_MAX_TEMP))
					)
				)
			) {

		if (dischargingStarted /*prevStatus==4*/) {
			lcd.setCursor(0, 0);
			lcd.write(byte(loadLenght + 4));

			lcd.setCursor(2, 0);
			if (batteryTemp > BATTERY_MAX_TEMP) {
				lcd.print("BHOT");

				lcd.setCursor(11, 1);
				lcd.print(" B");

				lcd.print(batteryTemp, 0);  // Battery Temp in °C
				lcd.write(byte(loadLenght + 3));
			} else {
				lcd.print("RHOT");

				lcd.setCursor(11, 1);
				lcd.print(" R");

				lcd.print(resistanceTemp, 0);  // Resitor Temp in °C
				lcd.write(byte(loadLenght + 3));
			}
		} else if (prevStatus != 1) {
			Serial.print("Battery temp: ");
			Serial.print(batteryTemp);
			Serial.print("*C, Resistance temp: ");
			Serial.print(resistanceTemp);
			Serial.println("*C");

			lcd.setCursor(0, 0);
			lcd.print("Res: ");
			lcd.print(resistanceTemp);
			lcd.write(byte(loadLenght + 3));
			lcd.print("C");

			lcd.setCursor(0, 1);
			lcd.print("Bat: ");
			lcd.print(batteryTemp, 2);
			lcd.write(byte(loadLenght + 3));
			lcd.print("C");
		}
	// No battery
	} else if (realBatVolt < NO_BATTERY_VOLTAGE) {
		if (dischargingStarted /*prevStatus==4*/) {
			lcd.setCursor(0, 0);
			lcd.write(byte(loadLenght + 0));

			lcd.setCursor(2, 0);
			lcd.print("Batt");
		} else if (prevStatus != 1) {
			Serial.println("No Battery!");

			lcd.setCursor(0, 0);
			lcd.print("No Battery!");
		}
		prevStatus = 1;

	// Battery votlage is wrong, probably wrong type of battery
	} else if (realBatVolt > batHigh) {
		if (dischargingStarted /*prevStatus==4*/) {
			lcd.setCursor(0, 0);
			lcd.write(byte(loadLenght + 2));

			lcd.setCursor(2, 0);
			lcd.print("High");
		} else if (prevStatus != 2) {
			lcd.setCursor(0, 0);
			lcd.print("High-V!");

			lcd.setCursor(0, 1);
			lcd.print("Wrong battery!");

			Serial.print("High-V!");

			Serial.print(" - ");

			Serial.print("Volt: ");
			Serial.print(realBatVolt, 2);  // display Battery Voltage in Volt
			Serial.print("V");

			Serial.print(" - ");

			Serial.print("DISCHARGING: ");
			Serial.println(mosfetStatus);     // display capacity in mAh

		}
		prevStatus = 2;
	// Battery is discharged
	} else if (realBatVolt < batLow  || lowRaised>NUMBER_OF_LOW_TO_RAISE) {
		if (dischargingStarted /*prevStatus==4*/) {
			lcd.setCursor(0, 0);
			lcd.write(byte(loadLenght + 1));

			lcd.setCursor(2, 0);
			lcd.print("Low ");

			// Need to display voltege battery when It's start discharged
			if (prevStatus != 3){
				lcd.setCursor(0, 1);
				lcd.print(realBatVolt, 2);  // display Battery Voltage in Volt
				lcd.print("V");
			}
		} else if (prevStatus != 3) {
			lcd.setCursor(0, 0);
			lcd.print("Low-V!");

			lcd.setCursor(0, 1);
			lcd.print(realBatVolt, 2);  // display Battery Voltage in Volt
			lcd.print("V");
		}



		Serial.print("Low-V!");

		Serial.print(" - ");

		Serial.print("Volt: ");
		Serial.print(realBatVolt, 2);  // display Battery Voltage in Volt
		Serial.print("V");

		Serial.print(" - ");
		Serial.print("lowRaised");
		Serial.print(lowRaised);  // display Battery Voltage in Volt

		Serial.print(" - ");

		Serial.print("DISCHARGING: ");
		Serial.println(mosfetStatus);     // display capacity in mAh

		prevStatus = 3;

	// Discharging time
	} else if (realBatVolt >= batLow && realBatVolt < batHigh) {
		// If prevState is low voltage and voltage less the tolerance not greater than battery low voltage cycle is finished
//		if (!(prevStatus == 3 && ((realBatVolt - tolerance) < batLow))) {
			lcd.clear();

			lcd.setCursor(0, 0);
			lcd.write(byte(loadingCursor));

			loadingCursor++;
			if (loadingCursor >= loadLenght)
				loadingCursor = 0;

			int percentage = (realBatVolt - batLow) * 100
					/ (startingVcc - batLow);

			if (percentage > 100)
				percentage = 100;

			lcd.setCursor(2, 0);
			lcd.print(percentage);
			lcd.print("%");

			lcd.setCursor(7, 0);

			lcd.print("mAh:");
			lcd.print(capacity, 1);     // display capacity in mAh

			lcd.setCursor(0, 1);
			lcd.print(realBatVolt, 2);  // display Battery Voltage in Volt
			lcd.print("V");

			lcd.print(" ");

			lcd.print(mA, 0);  // display current in mA
			lcd.print("mA");

			if ((USING_BATTERY_TERMISTOR && lastTempVisualizedBattery < 3)) {
				lcd.print(" B");

				lcd.print(batteryTemp, 0);  // Battery Temp in °C
				lcd.write(byte(loadLenght + 3));

			} else if ((USING_RESISTO_TERMISTOR && lastTempVisualizedBattery < 7)) {
				lcd.print(" R");

				lcd.print(resistanceTemp, 0);  // Resitor Temp in °C
				lcd.write(byte(loadLenght + 3));
			}
			lastTempVisualizedBattery++;
			if (lastTempVisualizedBattery >= 7) {
				lastTempVisualizedBattery = 0;
			}

			Serial.print("Volt: ");
			Serial.print(realBatVolt, 2);  // display Battery Voltage + res voltage in Volt
			Serial.print("V");

			Serial.print(" - ");

			Serial.print("B Volt: ");
			Serial.print(batVolt, 2);  // display Battery Voltage in Volt
			Serial.print("V");

			Serial.print(" - ");

			Serial.print("Res Volt: ");
			Serial.print(resVolt, 2);  // display Resistor Voltage in Volt
			Serial.print("V");

			Serial.print(" - ");

			Serial.print("Curr: ");
			Serial.print(mA, 0);  // display current in mA
			Serial.print("mA");

			Serial.print(" - ");

			Serial.print("mAh: ");
			Serial.print(capacity, 1);     // display capacity in mAh

			Serial.print(" - ");

			Serial.print("DISCHARGING: ");
			Serial.print(mosfetStatus);     // display mosfet status

			Serial.print(" - ");

			Serial.print("Battery temp: ");
			Serial.print(batteryTemp, 2);     // display battery temp

			Serial.print(" - ");

			Serial.print("Resistance temp: ");
			Serial.println(resistanceTemp, 2);     // display resistance temp
//		}
		prevStatus = 4;
	}
}
//******************************Buzzer Beep Function *********************************************************

void beep(unsigned char delay_time) {
	analogWrite(9, 20);      // PWM signal to generate beep tone
	delay(delay_time);          // wait for a delayms ms
	analogWrite(BUZZER_PIN, 0);  // 0 turns it off
	delay(delay_time);          // wait for a delayms ms
}

long readVcc() {
	// Read 1.1V reference against AVcc
	// set the reference to Vcc and the measurement to the internal 1.1V reference
#if defined(__AVR_ATmega32U4__) || defined(__AVR_ATmega1280__) || defined(__AVR_ATmega2560__)
	ADMUX = _BV(REFS0) | _BV(MUX4) | _BV(MUX3) | _BV(MUX2) | _BV(MUX1);
#elif defined (__AVR_ATtiny24__) || defined(__AVR_ATtiny44__) || defined(__AVR_ATtiny84__)
	ADMUX = _BV(MUX5) | _BV(MUX0);
#else
	ADMUX = _BV(REFS0) | _BV(MUX3) | _BV(MUX2) | _BV(MUX1);
#endif

	delay(2); // Wait for Vref to settle
	ADCSRA |= _BV(ADSC); // Start conversion
	while (bit_is_set(ADCSRA, ADSC))
		; // measuring

	uint8_t low = ADCL; // must read ADCL first - it then locks ADCH
	uint8_t high = ADCH; // unlocks both

	long result = (high << 8) | low;

	result = 1125300L / result; // Calculate Vcc (in mV); 1125300 = 1.1*1023*1000
	return result; // Vcc in millivolts
}

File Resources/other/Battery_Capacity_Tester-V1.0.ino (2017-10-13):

//>>>>>>>>>>>>>>>>>>>>>>>>>>>>>>>>>>>>>>>>>>>>>>>>>>>>>
// ARDUINO BATTERY CAPACITY TESTER
//Version-1.0
//by deba168,INDIA
//Dated : 04/09/2016
//>>>>>>>>>>>>>>>>>>>>>>>>>>>>>>>>>>>>>>>>>>>>>>>>>>>>>

#include "U8glib.h"
#define MOSFET_Pin 2
#define Bat_Pin A0
#define Res_Pin A1
#define Buzzer_Pin 9
U8GLIB_SH1106_128X64 u8g(U8G_I2C_OPT_NONE);  // I2C / TWI  
float Capacity = 0.0; // Capacity in mAh
float Res_Value = 10.0;  // Resistor Value in Ohm
float Vcc = 4.64; // Voltage of Arduino 5V pin ( Mesured by Multimeter )
float Current = 0.0; // Current in Amp
float mA=0;         // Current in mA
float Bat_Volt = 0.0;  // Battery Voltage 
float Res_Volt = 0.0;  // Voltage at lower end of the Resistor 
float Bat_High = 4.3; // Battery High Voltage
float Bat_Low = 2.9; // Discharge Cut Off Voltage
unsigned long previousMillis = 0; // Previous time in ms
unsigned long millisPassed = 0;  // Current time in ms
float sample1 =0;
float sample2= 0;
int x = 0;
int row = 0;

//************************ OLED Display Draw Function *******************************************************
void draw(void) {
   u8g.setFont(u8g_font_fub14r); // select font
   if ( Bat_Volt < 1){
    u8g.setPrintPos(10,40);        // set position
    u8g.println("No Battery!"); 
   }
   else if ( Bat_Volt > Bat_High){
    u8g.setPrintPos(25,40);        // set position
    u8g.println("High-V!"); 
   }
   else if(Bat_Volt < Bat_Low){
    u8g.setPrintPos(25,40);        // set position
    u8g.println("Low-V!"); 
   }
   else if(Bat_Volt >= Bat_Low && Bat_Volt < Bat_High  ){
      
   u8g.drawStr(0, 20, "Volt: ");   // put string of display at position X, Y
   u8g.drawStr(0, 40, "Curr: ");
   u8g.drawStr(0, 60, "mAh: ");
   u8g.setPrintPos(58,20);        // set position
   u8g.print( Bat_Volt,2);  // display Battery Voltage in Volt
   u8g.println("V"); 
   u8g.setPrintPos(58,40);        // set position
   u8g.print( mA,0);  // display current in mA
   u8g.println("mA"); 
   u8g.setPrintPos(58, 60);        // set position
   u8g.print( Capacity ,1);     // display capacity in mAh
  
}
}
//******************************Buzzer Beep Function *********************************************************

  void beep(unsigned char delay_time){
  analogWrite(9, 20);      // PWM signal to generate beep tone
  delay(delay_time);          // wait for a delayms ms
  analogWrite(Buzzer_Pin, 0);  // 0 turns it off
  delay(delay_time);          // wait for a delayms ms  

}  

//*******************************Setup Function ***************************************************************
  
  void setup() {
   Serial.begin(9600);
   pinMode(MOSFET_Pin, OUTPUT);
   pinMode(Buzzer_Pin, OUTPUT);
   digitalWrite(MOSFET_Pin, LOW);  // MOSFET is off during the start
   Serial.println("CLEARDATA");
   Serial.println("LABEL,Time,Bat_Volt,capacity");
   
   //Serial.println("Arduino Battery Capacity Tester v1.0");
   //Serial.println("BattVolt Current mAh");
  }
  //********************************Main Loop Function***********************************************************
  void loop() {
 // Vcc = readVcc()/1000.0; // Conevrrt mV to Volt

  
  // Voltage devider Out = Bat_Volt * R2/(R1+R2 ) // R1 =10K and R2 =10K 
  
  //************ Measuring Battery Voltage ***********
  
  for(int i=0;i< 100;i++)
  {
   sample1=sample1+analogRead(Bat_Pin); //read the voltage from the divider circuit
   delay (2);
  }
  sample1=sample1/100; 
  Bat_Volt = 2* sample1 *Vcc/ 1024.0; 

  // *********  Measuring Resistor Voltage ***********

   for(int i=0;i< 100;i++)
  {
   sample2=sample2+analogRead(Res_Pin); //read the voltage from the divider circuit
   delay (2);
  }
  sample2=sample2/100;
  Res_Volt = 2* sample2 * Vcc/ 1024.0;

  //********************* Checking the different conditions *************
  
  if ( Bat_Volt > Bat_High){
    digitalWrite(MOSFET_Pin, LOW); // Turned Off the MOSFET // No discharge 
    beep(200);
    Serial.println( "Warning High-V! ");
    delay(1000);
   }
   
   else if(Bat_Volt < Bat_Low){
      digitalWrite(MOSFET_Pin, LOW);
      beep(200);
      Serial.println( "Warning Low-V! ");
      delay(1000);
  }
  else if(Bat_Volt > Bat_Low && Bat_Volt < Bat_High  ) { // Check if the battery voltage is within the safe limit
      digitalWrite(MOSFET_Pin, HIGH);
      millisPassed = millis() - previousMillis;
      Current = (Bat_Volt - Res_Volt) / Res_Value;
      mA = Current * 1000.0 ;
      Capacity = Capacity + mA * (millisPassed / 3600000.0); // 1 Hour = 3600000ms
      previousMillis = millis();
      Serial.print("DATA,TIME,"); Serial.print(Bat_Volt); Serial.print(","); Serial.println(Capacity);
      row++;
      x++;
      delay(4000); 
 
     }
  
   //**************************************************

  u8g.firstPage();  
  do {
    draw();
  } while( u8g.nextPage() );
  
 //*************************************************
 }    

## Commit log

2017-10-16 Some fix on documentation
    [BTester.fzz]
2017-10-16 Added note
    [BTester.fzz]
2017-10-25 Minor change
    [BTester.fzz]
2017-10-25 Version 0.2 with battery selection button. And reset.
    [BTesterV02.fzz]
2017-10-25 Battery selection
2017-10-25 Battery tester v02 breadboard
2017-10-27 Version0.2 with prefored board
    [BTester.fzz, BTesterV02.fzz, PTesterV02.fzz]
2017-10-29 6v battery tested
2017-10-29 More temperature of power resistor (for 6v lead acid battery)
2017-10-29 Fix heat wait
